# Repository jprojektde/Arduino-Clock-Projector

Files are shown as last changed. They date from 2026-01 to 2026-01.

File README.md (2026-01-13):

# Arduino-Clock-Projector  
A simple little projector module for your DIY alarm clock 🕒✨

Building an alarm clock **with a real wall projector** is surprisingly hard.  
Until now there wasn’t really an easy way to just *buy a small module* that can project the time cleanly.

So I went looking and found this **cheap LED projector lamp on AliExpress**:  
https://de.aliexpress.com/item/1005009155662454.html  

It’s super affordable, but it also has a few downsides:

- It’s a **7-segment display**
- You only get **3 full digits**
- The first digit is basically a “1” made from only **two segments**
- Plus the **":"** in the middle

That said — the important part is:  
✅ We only need the **LCD**, the **rubber contact piece**, and the **lens** from the projector.

---

## Pictures

Here are a few pictures from the project:

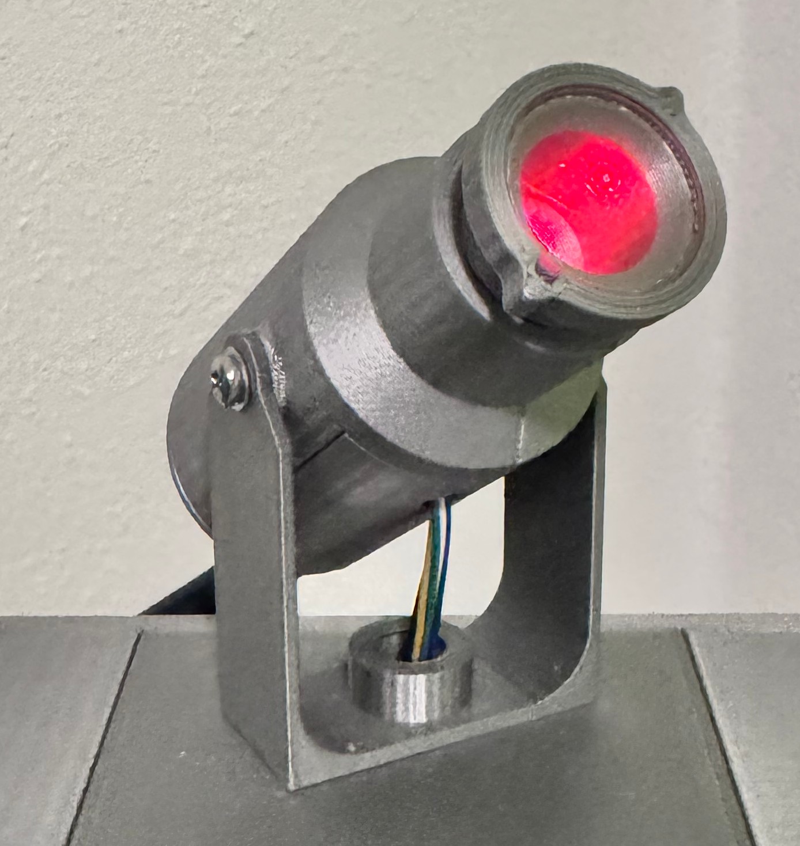
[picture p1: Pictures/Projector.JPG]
Projector Module
  
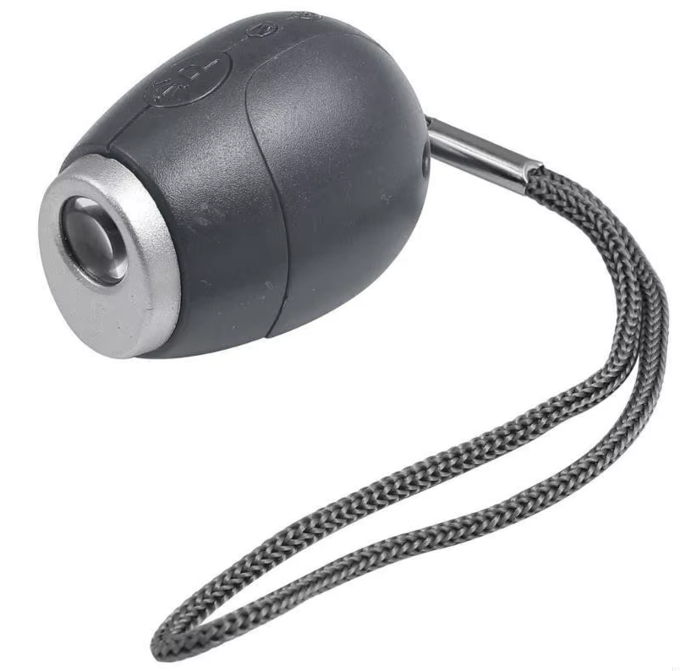
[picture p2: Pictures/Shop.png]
Shop Listing
  
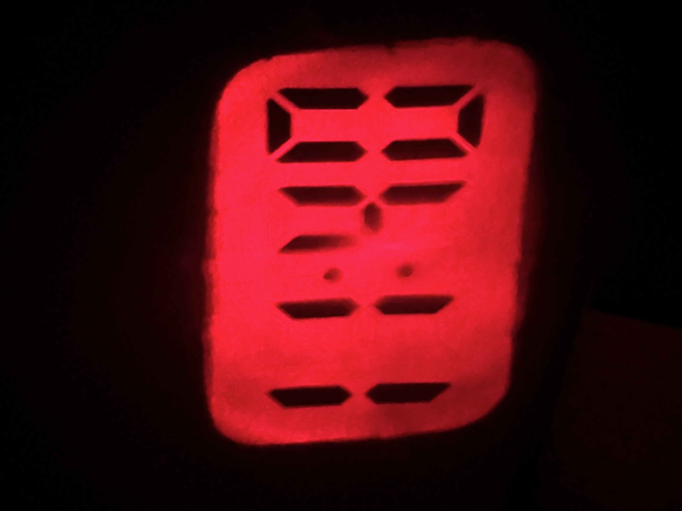
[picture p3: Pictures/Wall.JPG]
Projection on the Wall


---

## What’s in this project?

I designed a custom PCB using the **HT1621 LCD driver**, and the rest of the build is done with **3D printed parts**.  
All required files are included in this repository.

For a nicer final look, you can also add a small glass plate (20×1.5mm) from AliExpress:  
https://de.aliexpress.com/item/1005003692263992.html  

---

## Testing it

I also included a small **Arduino test sketch** so you can try it immediately.

**Basic setup:**
- Connect the module to your Arduino
- Add a small resistor for the LED
- Power it up and enjoy the magic 😄

If the image isn’t sharp, just **twist the lens holder** until the projection is in focus.

From my experience, the LED works best in darker rooms and projects clearly for about **3–4 meters**.

---

## LED recommendation (important!)

It’s **really important** to use an LED with a **15° viewing angle**, otherwise the projection will look weak or blurry.

These LEDs work great (I used them myself):

**Green:**  
https://www.reichelt.de/de/de/shop/produkt/led_5_mm_bedrahtet_gruen_43300_mcd_15_-230982  

**Classic Red:**  
https://www.reichelt.de/de/de/shop/produkt/led_5mm_bedrahtet_rot_20000_mcd_15_-361605?nbc=1  

---

Have fun testing and tinkering! 😄🔧

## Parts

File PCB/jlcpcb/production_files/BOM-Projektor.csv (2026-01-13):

Comment | Designator | Footprint | LCSC
100nF | C1 | C_0402_1005Metric | C1525
56 | R4 | R_1206_3216Metric | C17995
AO3400A | Q1 | SOT-23 | C20917
100 | R2 | R_0402_1005Metric | C25076
10k | R1,R3 | R_0402_1005Metric | C25744
HT1621B | U2 | SSOP-48_7.5x15.9mm_P0.635mm | C7873

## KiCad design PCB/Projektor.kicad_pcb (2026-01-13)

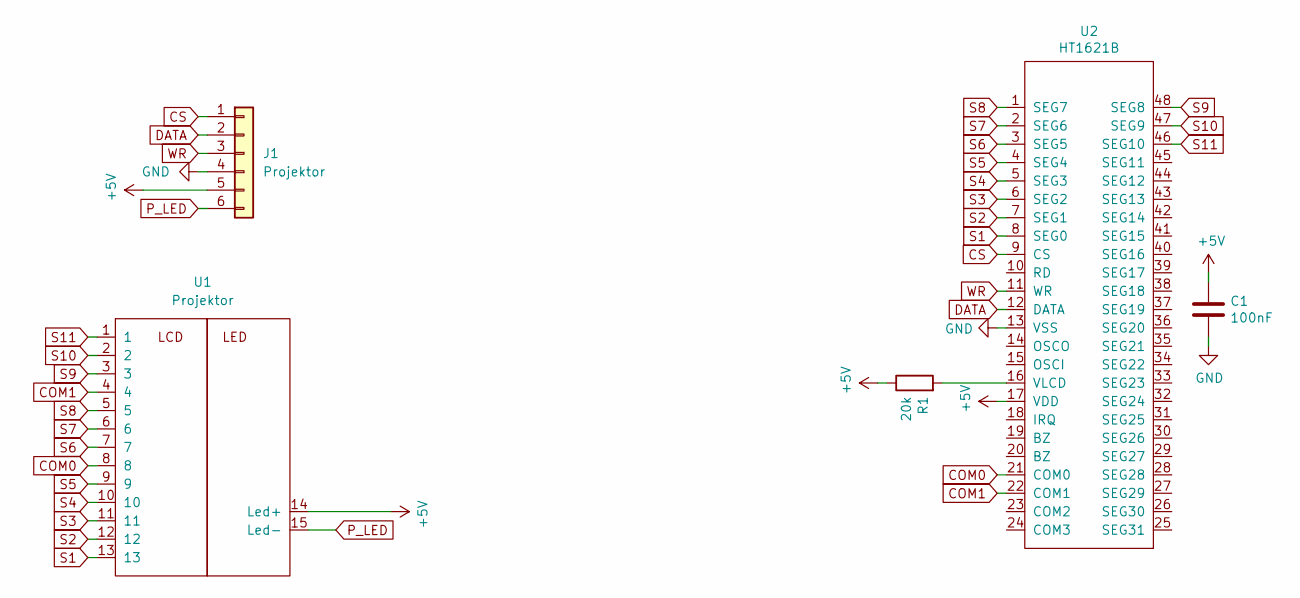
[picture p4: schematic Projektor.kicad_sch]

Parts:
C1: 100nF; C_0603_1608Metric
J1: Projektor; Molex_PicoBlade_53047-0610_1x06_P1.25mm_Vertical
R1: 20k; R_0603_1608Metric
U1: Projektor; Projektor_Controlliert
U2: HT1621B; SSOP-48_7.5x15.9mm_P0.635mm

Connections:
+5V: C1.1, J1.5, R1.1, U1.14 (Led+), U2.17 (VDD)
COM0: U1.8, U2.21 (COM0)
COM1: U1.4, U2.22 (COM1)
CS: J1.1, U2.9 (CS)
DATA: J1.2, U2.12 (DATA)
GND: C1.2, J1.4, U2.13 (VSS)
unnamed: R1.2, U2.16 (VLCD)
P_LED: J1.6, U1.15 (Led-)
S1: U1.13, U2.8 (SEG0)
S2: U1.12, U2.7 (SEG1)
S3: U1.11, U2.6 (SEG2)
S4: U1.10, U2.5 (SEG3)
S5: U1.9, U2.4 (SEG4)
S6: U1.7, U2.3 (SEG5)
S7: U1.6, U2.2 (SEG6)
S8: U1.5, U2.1 (SEG7)
S9: U1.3, U2.48 (SEG8)
S10: U1.2, U2.47 (SEG9)
S11: U1.1, U2.46 (SEG10)
WR: J1.3, U2.11 (WR)

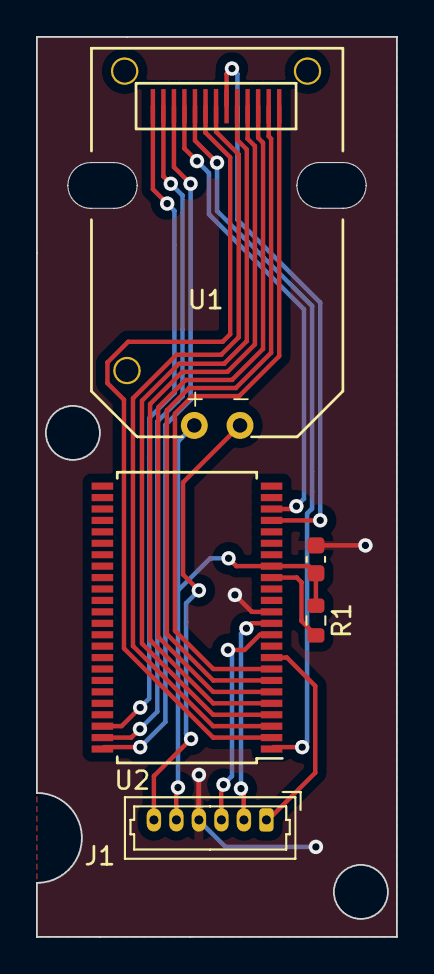
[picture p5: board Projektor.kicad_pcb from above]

Board: 2 copper layers, 20.0 x 50.0 mm, 5 parts (0 on the bottom side), 20 nets.

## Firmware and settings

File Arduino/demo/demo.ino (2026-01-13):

#include "Projektor.h"



int pin_CS = 13;
int pin_WR = 12;
int pin_DATA = 11;




void setup() {
  pinMode(pin_CS,OUTPUT);
  pinMode(pin_WR,OUTPUT);
  pinMode(pin_DATA,OUTPUT);

  Init_1621(pin_CS,pin_WR,pin_DATA);
  

}

void loop() {
  // put your main code here, to run repeatedly:

  Init_1621(pin_CS,pin_WR,pin_DATA);

  char buffer[10]={0};

  sprintf(buffer,"%02d%c%02d",12,':',34);

  Projektor_Clear_Buffer();
  Projektor_display(buffer);
  Projektor_Send_Buffer();

  delay(5000);

}
